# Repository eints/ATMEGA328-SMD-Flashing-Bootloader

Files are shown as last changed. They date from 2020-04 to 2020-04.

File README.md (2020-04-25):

# ATMEGA328 SMD Bootloader Flashing

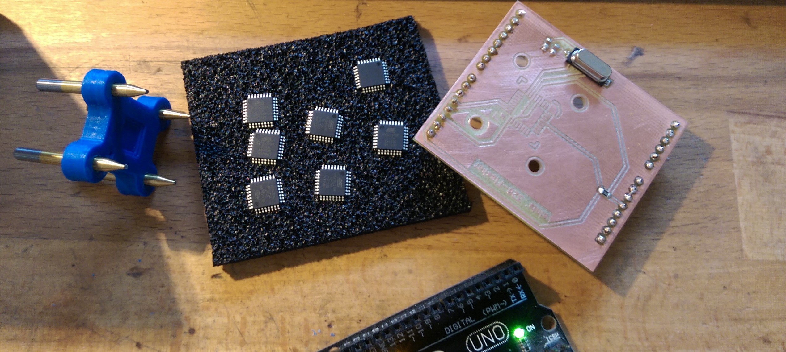
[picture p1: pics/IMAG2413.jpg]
Uno Flashing Shield


This is a little project I built to be able to flash my ATMEGA328 SMD chips with an Arduino bootloader.
There are professional solutions like here https://www.youtube.com/watch?v=GFyr9tVEHzQ. 
But for the 5 to 10 Chips I need to flash from time to time I couldn't justify to buy such a thing. 
I wanted to have something cheap and easy to use. Thus I built my own simple board.

I always use the [Optiloader](https://github.com/WestfW/OptiLoader). 
To flash it to an out-of-factory chip you need to connect the RESET, MISO, MOSI & SCK pins. 
Additionally a crystal and +5V are required. I designed this simple shield for an Uno with the mentioned connections.

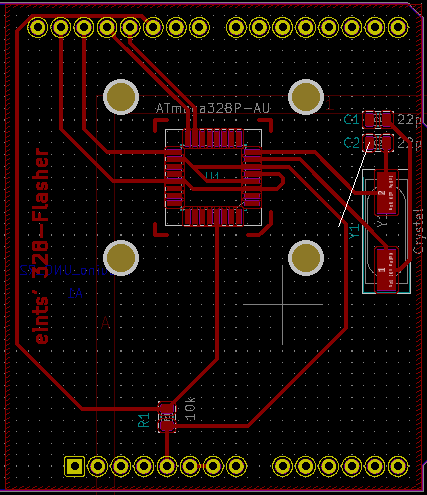
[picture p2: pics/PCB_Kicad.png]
 

The used components are just a 10k pull-up resistor for the RESET pin, a 16MHz crystal with two 22pF capacitors and a few pin headers.

I milled the PCB on my desktop CNC with a 60° V-bit. The resulting PCB looks like this:
| PCB Front | PCB Back with magnet  |
|---|---|
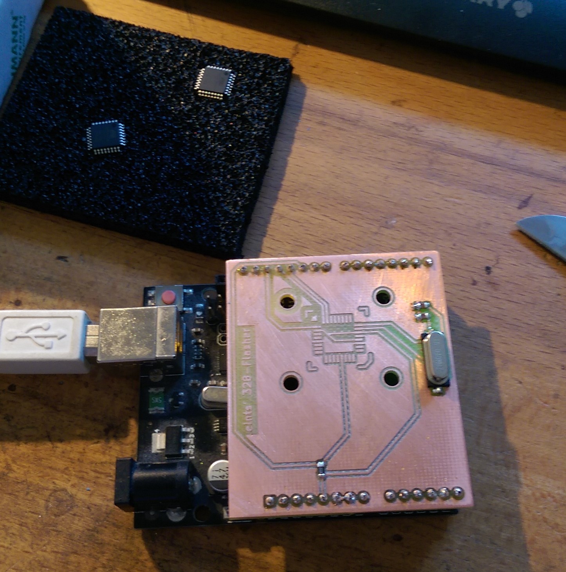
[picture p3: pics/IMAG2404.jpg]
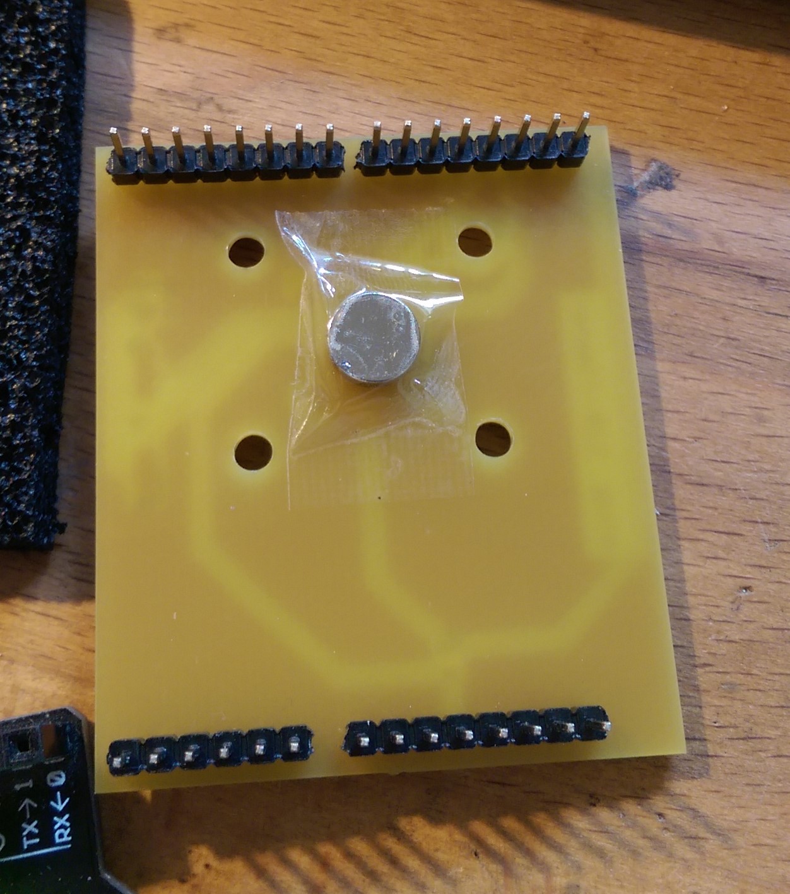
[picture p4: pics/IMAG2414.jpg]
|   |   | 

To press the chip onto the PCB the 3D printed chip holder is used.

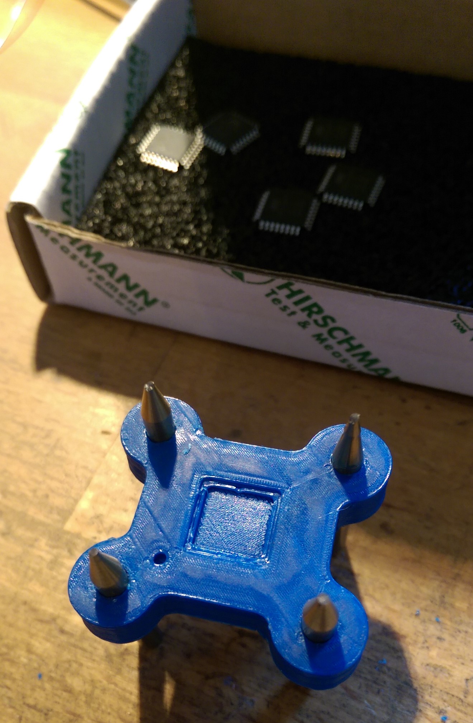
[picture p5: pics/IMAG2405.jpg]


The chip should fit perfectly in the recess. At first the recess was slightly to large. 
I could have reprinted the holder with a smaller recess but roughing the inner walls of the recess with a knives solved the problem for me. 
Now the chip kind of clicks in.
The hole in one corner of the holder marks the chip orientation. It is aligned with the marking impression on the top side of the chip.

| Inserting Chip | Chip Inserted  |
|---|---|
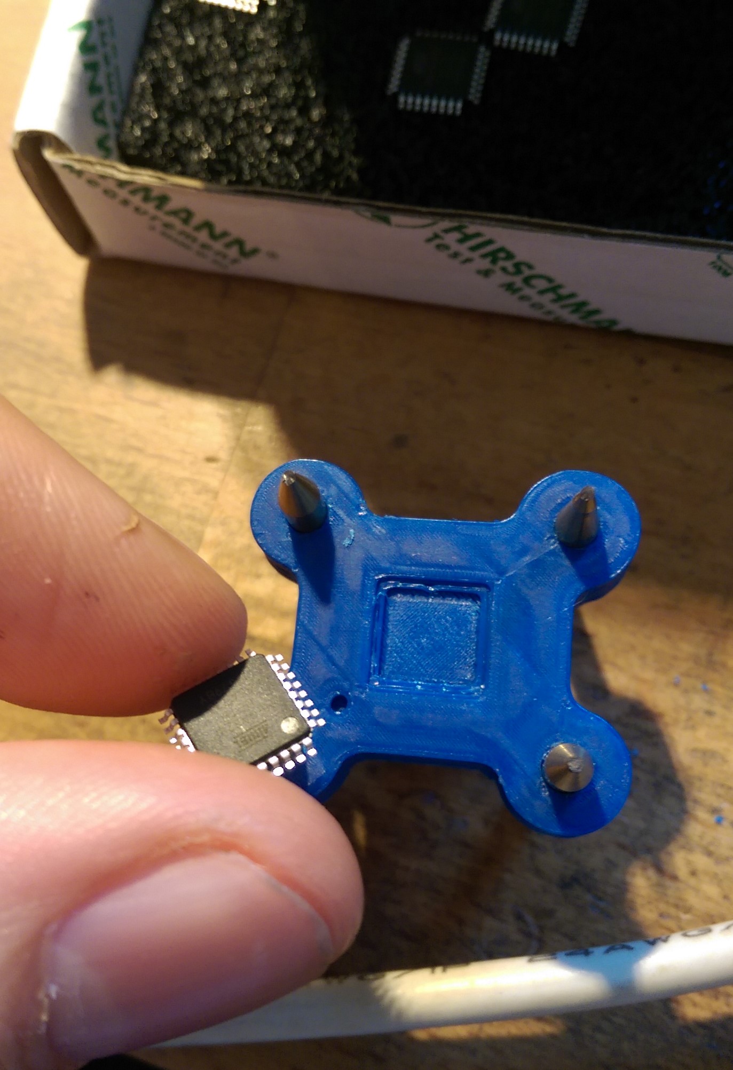
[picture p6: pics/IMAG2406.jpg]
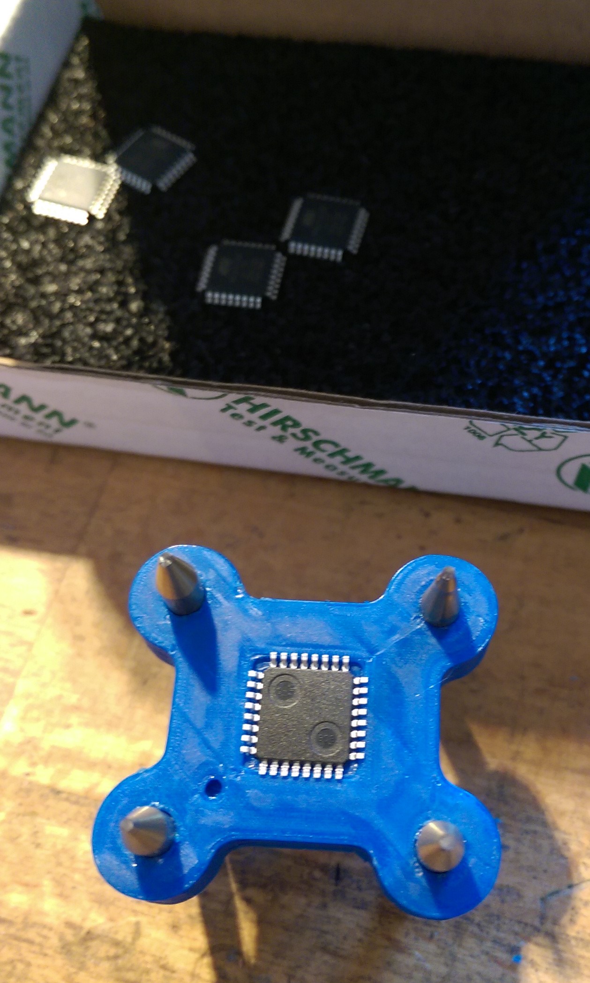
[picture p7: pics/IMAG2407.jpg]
|   |   | 

Four bolts guarantee the alignment of chip and PCB. I use broken drill/mill bits from my CNC. 
Magnets in the holder and on the backside of the PCB apply slight pressure to ensure a reliable contact.

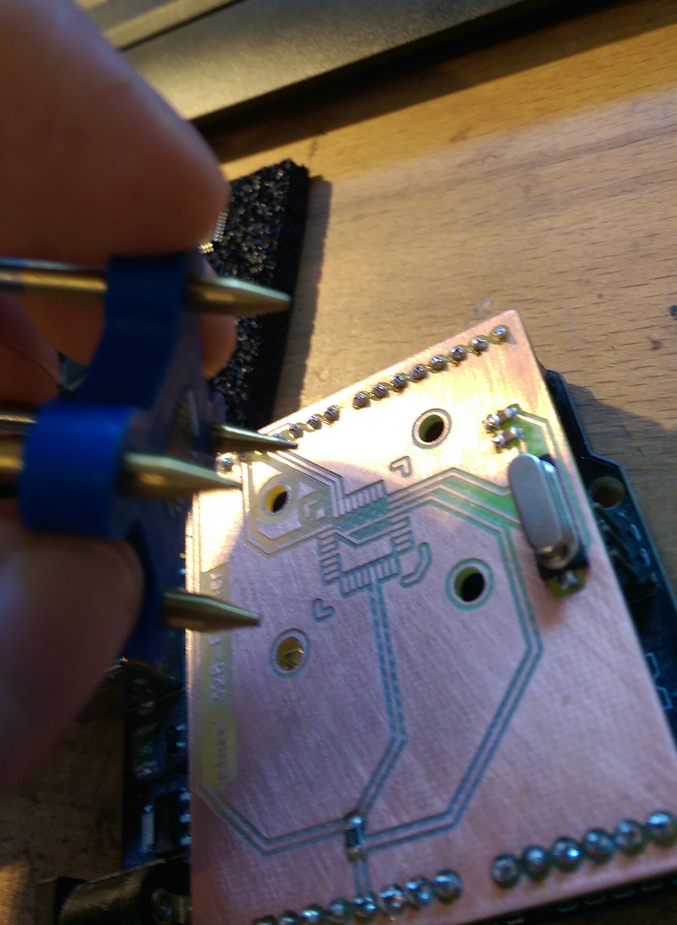
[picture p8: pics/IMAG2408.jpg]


When the chip is in place the bootloader is flashed.

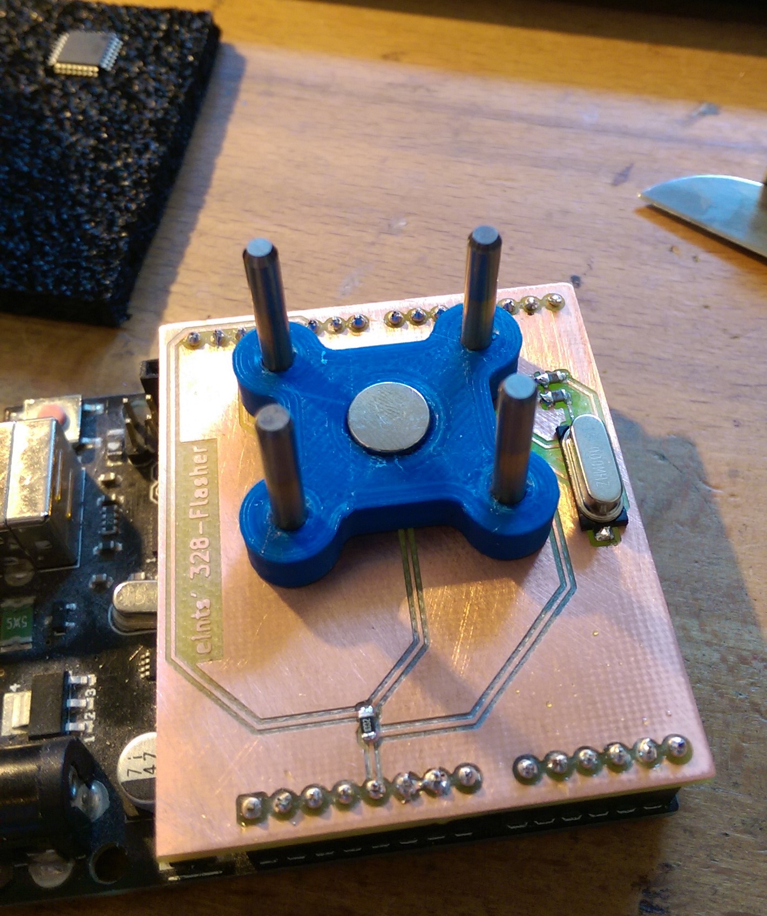
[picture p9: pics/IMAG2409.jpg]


Here is the flashed chip ready to be used in the next project! 

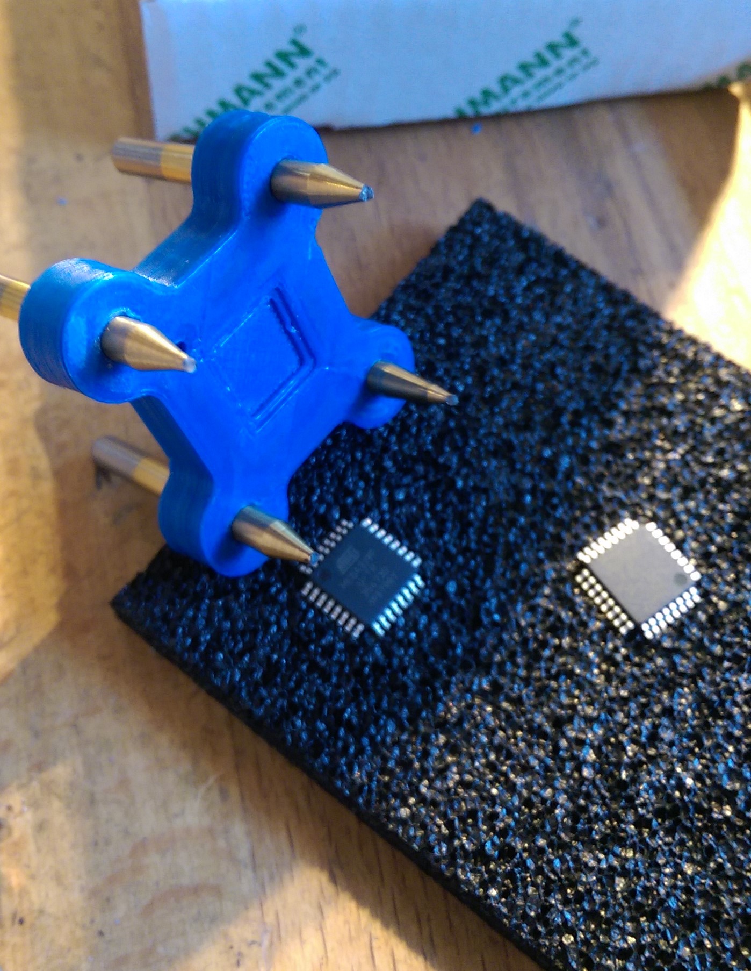
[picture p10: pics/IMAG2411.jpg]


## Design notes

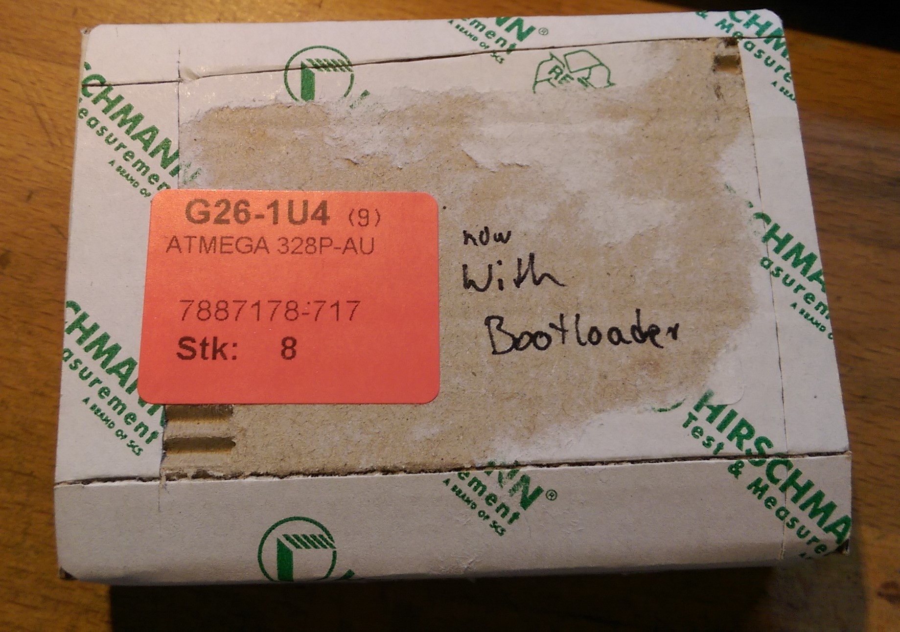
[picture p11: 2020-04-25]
pics/IMAG2415.jpg

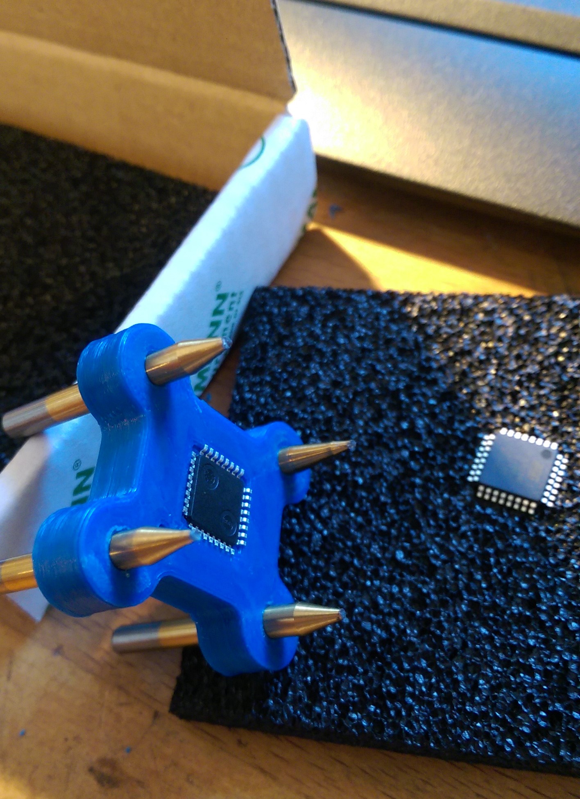
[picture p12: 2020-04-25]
pics/IMAG2410.jpg

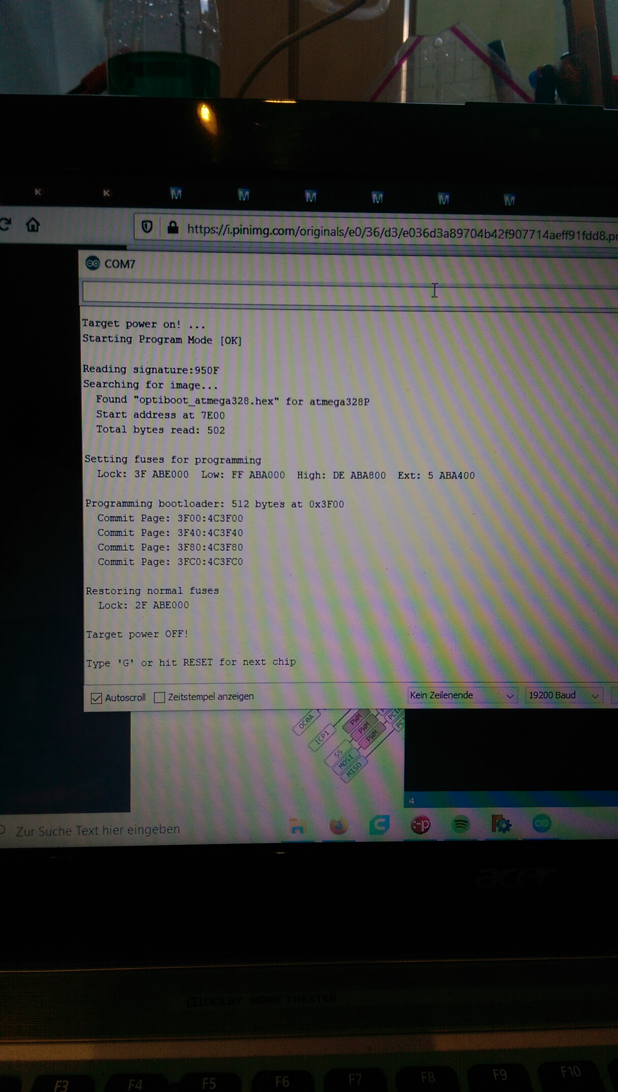
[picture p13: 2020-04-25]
pics/IMAG2412.jpg

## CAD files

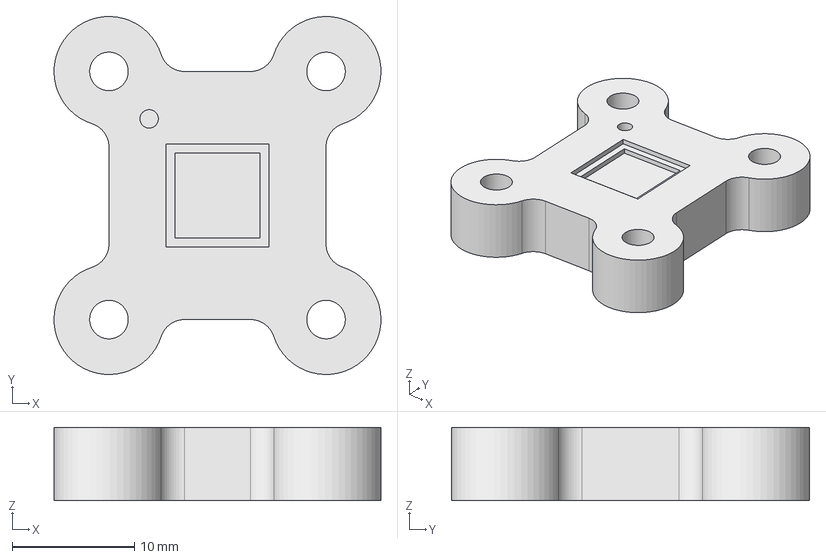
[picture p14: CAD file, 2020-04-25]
ChipHolder/ChipHolder.FCStd
26.8 x 29.3 x 6.00 mm

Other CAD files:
ChipHolder/ChipHolder.stl
